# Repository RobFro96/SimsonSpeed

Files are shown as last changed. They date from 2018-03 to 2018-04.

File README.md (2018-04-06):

# SimsonSpeed
__Digitaler Tachometer, Drehzahlmesser und Ganganzeige für Simson-Mopeds__

Beschreibung des Grundprinzips: siehe <http://robert-fromm.info/?post=elec_simsonspeed>
Weitere Artikel auf meiner Homepage werden folgen.

# Inhalt des Repositories
## ccs-project/
Programmierung des MSP430. Code Composer Studio Projekt.

## eagle/
Schaltplan und Layout der Leiterplatte.

## gfx/
Bilddateien, Skripte zum Umwandeln der Bilddateien in Byte-Arrays zum Einfügen in C-Dateien.

## tester/
Platine mit Arduino Nano zum Simulieren der Lichtmaschine und Reed-Kontakt. Ermöglicht einfaches Testen der Anwendungen.

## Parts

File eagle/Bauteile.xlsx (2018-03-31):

Bauteil | Wert | Beschreibung | Kosten | Artikel | Spalte1 | Spalte2
BL | amber | Hintergrundbeleuchtung | 2.70 € | EA LED39X41-A | x | x
C1 | 1µ | LCD VLCD | 0.02 € | SM 1,0/63RAD | x | x
C2 | 1µ | LCD VB1 | 0.02 € | SM 1,0/63RAD | x | x
C3 | 1µ | LCD VB0 | 0.02 € | SM 1,0/63RAD | x | x
C4 | 100n | MSP430 | 0.03 € | Z5U-5 10N | x | x
C5 | 100µ, 25 V | Eingang Lichtmaschine | 0.03 € | RAD 100/25 | x | x
C6 | 10µ | Ausgang Spannungsregler | 0.03 € | SM 10/16RAD | x | x
D1 | Si | Lichtmaschine Eingang | 0.02 € | 1N 4001 | x | x
D2 | Schottky | Strompfad Batterie | 0.04 € | BAT 42 | x | x
D3 | Schottky | Strompfad Spannungswandler | 0.04 € | BAT 42 | x | x
IC1 | regelbar | Spannungsregler | 0.19 € | LM 317 TO 92 | x | x
IC2 | DIP | MSP430 G2553 | 2.82 € | Conrad: 1010488 - 62
IC2X | DIP20 | IC-Sockel | 0.07 € | GS 20 | x | x
IC3 | transflektiv | Display | 11.90 € | EA DOGS102W-6 | x | x
OK1 | Doppelkoppler | Optokoppler Drehzahl, Reed | 0.45 € | ILD 74 | x | x
R1 | 100 | OK Reed R=(3.3-1.2)/20m=105 | 0.03 € | 1/4W 100 | x | x
R2 | 10k | Pullup OK Reed | 0.03 € | 1/4W 10K | x | x
R3 | 390 | OK Lichtmaschine R=(20-1.2)/50m=380, I=(6*w(2)-1.2)/380=8.91mA | 0.03 € | 1/4W 390 | x | x
R4 | 10k | Pullup OK Lichtmaschine | 0.03 € | 1/4W 10K | x | x
R5 | 10k | Pullup Reset MSP430 | 0.03 € | 1/4W 10K | x | x
R6 | 200 | Spannungsregler Out <> ADJ | 0.03 € | 1/4W 200 | x | x
R7 | 390 | Spannungsregler ADJ <> GND | 0.03 € | 1/4W 390 | x | x
R8 | 30 | Beleuchtung | 0.03 € | 1/4W 30 | x | x
R9 | 30 | Beleuchtung | 0.03 € | 1/4W 30 | x | x
X1 |  | Drehencoder | 0.38 € | Amazon: B0085I4D5C
X2 |  | Klinkeneinbaubuchse | 0.28 € | EBOSV 63 | x
X3 | 22 Pins | Buchsenleiste Display 16 + 2x2 Pins | 0.99 € | MPE 115-1-022 | x | x
X4 |  | Klinkenstecker | 0.20 € | RND 205-00619 | x | x
X5 |  | 2x Leitungsverteiler | 0.12 € | LV-R | x | x
X6 |  | Knopfzellenhalter | 0.43 € | KZH 20-1 | x | x
X7 |  | Knopfzelle | 0.44 € | CR 2032 | x | x

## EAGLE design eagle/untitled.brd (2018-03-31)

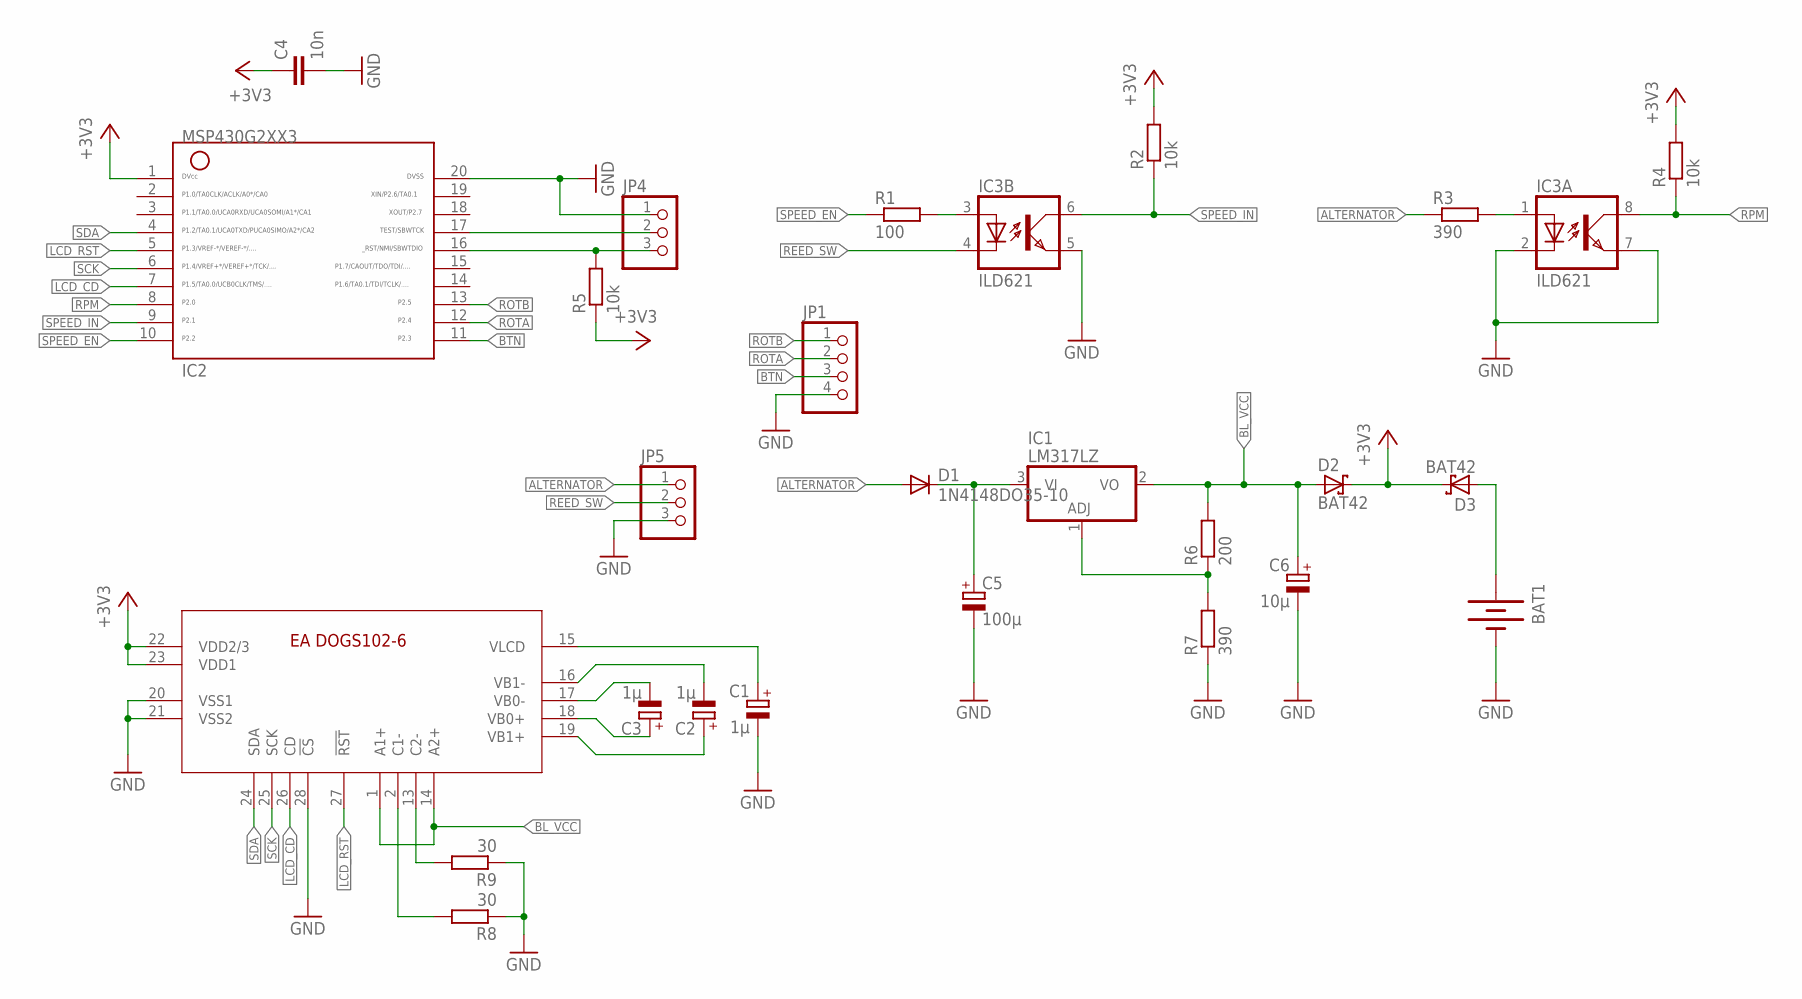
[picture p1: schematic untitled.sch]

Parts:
BAT1: BATTERY20PTH; BATTCOM_20MM_PTH
C1, C2, C3: 1µ; E2-4
C4: 10n; C050-024X044
C5: 100µ; E2,5-6E
C6: 10µ; E2-4
D1: 1N4148DO35-10; DO35-10
D2, D3: BAT42; DO35-10
IC1: LM317LZ; TO92
IC2: G2XX3---N20; N20
IC3: ILD621; DIL08
JP1: PINHD-1X4; 1X04
JP4, JP5: PINHD-1X3; 1X03
R1: 100; 0204/7
R2, R4, R5: 10k; 0204/7
R3, R7: 390; 0204/7
R6: 200; 0204/7
R8, R9: 30; 0204/7
U$1: EA-DOG102-6; EA_DOGS102-6

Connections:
+3V3: C4.1, D2.C, D3.C, IC2.1, R2.2, R4.2, R5.1, U$1.22 (VDD2/3), U$1.23 (VDD1)
ALTERNATOR: D1.A, JP5.1, R3.1
BL_VCC: C6.+, D2.A, IC1.2 (VO), R6.2, U$1.1 (A1+), U$1.14 (A2+)
BTN: IC2.11, JP1.3
GND: BAT1.2 (-), C1.-, C4.2, C5.-, C6.-, IC2.20, IC3.2 (C), IC3.5 (EMIT), IC3.7 (EMIT), JP1.4, JP4.1, JP5.3, R7.1, R8.1, R9.1, U$1.20 (VSS1), U$1.21 (VSS2), U$1.28 (!CS!)
LCD_CD: IC2.7, U$1.26 (CD)
LCD_RST: IC2.5, U$1.27 (!RST!)
unnamed: IC2.16, JP4.3, R5.2
unnamed: IC2.17, JP4.2
unnamed: C1.+, U$1.15 (VLCD)
unnamed: IC3.3 (A), R1.2
unnamed: C3.-, U$1.17 (VB0-)
unnamed: C3.+, U$1.18 (VB0+)
unnamed: C2.-, U$1.16 (VB1-)
unnamed: IC1.1 (ADJ), R6.1, R7.2
unnamed: C5.+, D1.C, IC1.3 (VI)
unnamed: BAT1.1 (+), D3.A
unnamed: IC3.1 (A), R3.2
unnamed: C2.+, U$1.19 (VB1+)
unnamed: R8.2, U$1.2 (C1-)
unnamed: R9.2, U$1.13 (C2-)
REED_SW: IC3.4 (C), JP5.2
ROTA: IC2.12, JP1.2
ROTB: IC2.13, JP1.1
RPM: IC2.8, IC3.8 (COL), R4.1
SCK: IC2.6, U$1.25 (SCK)
SDA: IC2.4, U$1.24 (SDA)
SPEED_EN: IC2.10, R1.1
SPEED_IN: IC2.9, IC3.6 (COL), R2.1

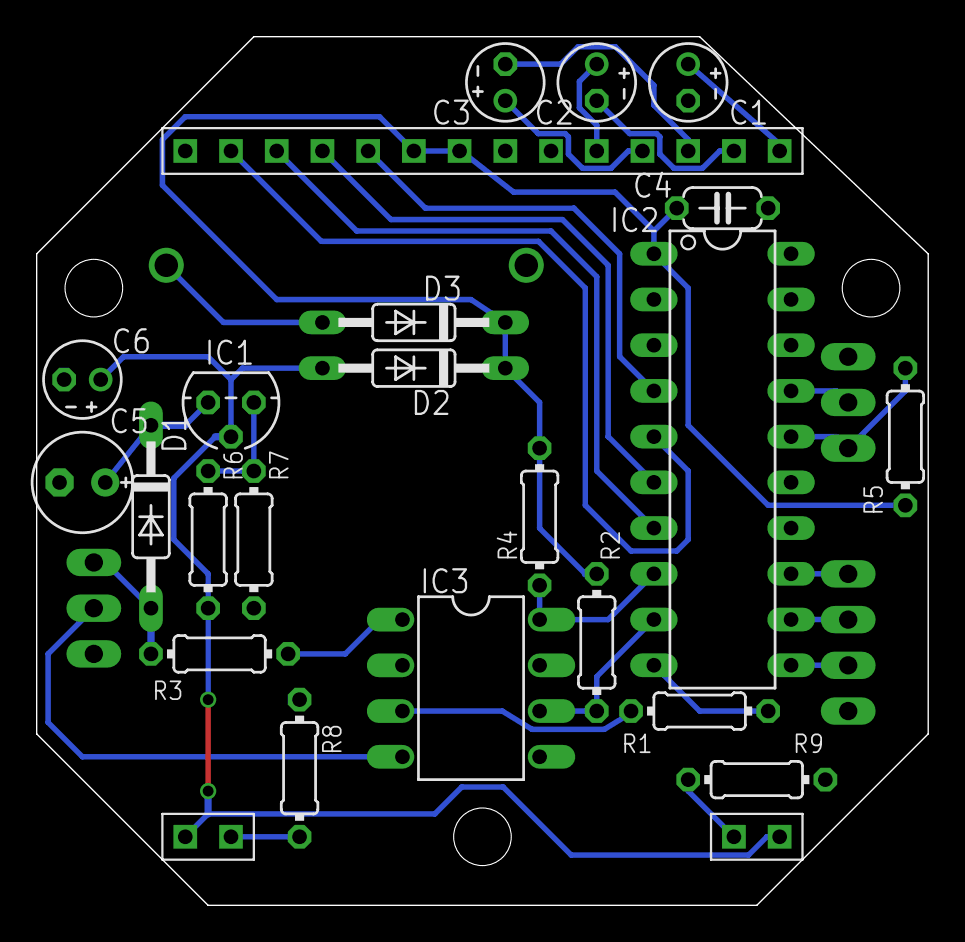
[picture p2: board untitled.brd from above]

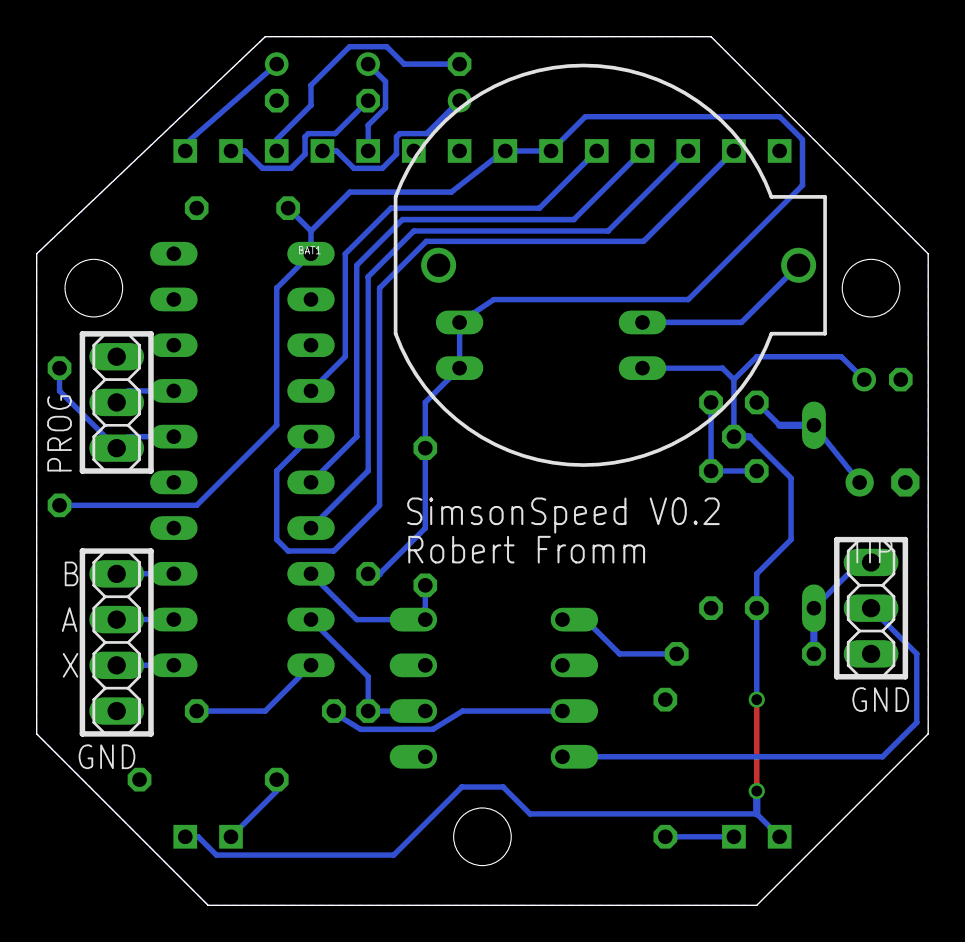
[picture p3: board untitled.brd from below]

Board: 2 copper layers, 49.5 x 48.3 mm, 26 parts (4 on the bottom side), 29 nets.

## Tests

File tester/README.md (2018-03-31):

Platine mit Arduino Nano zum Simulieren der Lichtmaschine und Reed-Kontakt.
Ermöglicht einfaches Testen der Anwendungen.

- Programmierung des Arduino Nanos: `arduino/`
- GUI zum Einstellen von RPM und Geschwindigkeit: `gui/`

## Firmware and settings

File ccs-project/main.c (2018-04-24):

#include <msp430.h>
#include <stdint.h>
#include "power.h"
#include "settings_menu.h"

/**
 * Hauptprogramm
 *
 * @return	Ende des Hauptprogramms wird nie erreicht -> kein Rückgabewert
 */

int main(void) {
	// Stopp Watchdog-Timer
 	WDTCTL = WDTPW | WDTHOLD;

	// 1 MHz Main Clock Kalibrierung setzen
	DCOCTL = CALDCO_1MHZ;
	BCSCTL1 = CALBC1_1MHZ;

	// 32kHz-Quartz an Pin 2.6, 2.7 deaktivieren, alle ungenutzten Pins -> Pullup-Widerstände
	P2SEL &= ~(BIT6 + BIT7);
	P1REN = BIT0 + BIT1 + BIT6 + BIT7;
	P2REN = BIT0 + BIT3 + BIT4 + BIT5 + BIT6 + BIT7;

	__enable_interrupt();

	// Initialisierung und Main-Loop findet im Modul power statt.
	setting_default();
	power_init();

	while (1) {
		power_main_loop();
	}
}

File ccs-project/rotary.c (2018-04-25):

#include <msp430.h>
#include <stdint.h>
#include "power.h"
#include "timer.h"

#include "rotary.h"


volatile uint8_t rotary_pressed = 0; //!< Gibt, an ob der Rotary gedrückt wurde. Muss manuell resettet werden.
volatile int16_t rotary_counter = 0; //!< Gibt die aktuelle Position des Drehgebers an. Kann manipuliert werden.

/**
 * Initialisierung der Rotary-Ansteuerung
 * Initialisierung der drei Pins, des Timers A0
 */
void rotary_init() {
	P2DIR &= ~(BIT3 + BIT4 + BIT5);
	P2REN |= (BIT3 + BIT4 + BIT5);
	P2OUT |= (BIT3 + BIT4 + BIT5);

	P2IE |= BIT3 + BIT4;
	P2IES &= ~(BIT3 + BIT4 + BIT5);
	P2IFG &= ~(BIT3 + BIT4 + BIT5);

	TA0CCTL0 = CCIE;
	TA0CCR0 = 100;
}

/**
 * Ausschalten der Pullups zum Stromsparen,
 * Ausschalten des Timer A0
 */
void rotary_disable() {
	P2IE &= ~(BIT4 + BIT5);
	P2OUT &= ~(BIT4 + BIT5);

	TA0CTL = 0;
}

/**
 * ISR für Port 2
 *
 * Pin 2.0 (RPM): Aufwachen im StandBy
 * Pin 2.3 (BTN): Aufwachen im StandBy, rotary_pressed setzen (Normalbetrieb)
 * Pin 2.4 (ROTA): Starten des Timers A0
 */
#pragma vector=PORT2_VECTOR
interrupt void PORT2_ISR() {
	// RPM-Pin
	if (P2IFG & BIT0) {
		P2IFG &= ~BIT0;
		if (power_sleeping) {
			__low_power_mode_off_on_exit();
		}
	}

	// Button
	if (P2IFG & BIT3) {
		P2IFG &= ~BIT3;
		if (power_sleeping) {
			__low_power_mode_off_on_exit();
		} else if (rpm_periodes[0] == 0xffff) {
			rotary_pressed = 1;
		}
	}

	// Rotary
	if (P2IFG & BIT4) {
		P2IFG &= ~BIT4;

		if (!(TA0CTL & MC_1)) {
			TA0CTL = TASSEL_2 + ID_3 + TACLR + MC_1;
		}
	}
}

/**
 * Timer A0 CCR0-Interrupt
 * Wird ausgelöst 800 µsec nach fallender Flanke an ROTA
 */
#pragma vector=TIMER0_A0_VECTOR
interrupt void TIMER0_A0_ISR() {
	TA0CTL = 0;

	if (rpm_periodes[0] != 0xffff)
		return;

	if (P2IN & BIT4) {
		if (P2IN & BIT5) {
			rotary_counter++;
		} else {
			rotary_counter--;
		}
	}

	P2IE |= BIT4;
}

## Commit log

2017-07-01 Started Gear Display
2017-07-02 Finished Gear Display
2017-07-05 Finished Power-Manager
2017-07-09 Minor Fixes, Changed Capacitive Touch to one button
    [main.c]
2017-11-03 Release Version 1.1 Changed Touch to Button
2018-03-31 Explicit Pullup on Push-Button
2018-03-31 Added EAGLE files
    [Bauteile.xlsx, untitled.brd, untitled.sch]
2018-04-07 ADD: Kommentare (auch Doxygen) des gesamten MSP430-Programms
2018-04-15 CHANGE: Unterordner lcd/ und mainscreen/ erstellt
2018-04-16 CONTINUED: Zeichen des Einstellungsmenu

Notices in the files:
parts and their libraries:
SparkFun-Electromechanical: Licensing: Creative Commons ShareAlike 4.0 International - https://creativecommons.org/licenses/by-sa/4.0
